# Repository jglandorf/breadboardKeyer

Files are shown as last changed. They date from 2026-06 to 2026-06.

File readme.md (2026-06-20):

## Breadboard Keyer Demo for [ARROW](https://w8rp.org/) Field Day
### A Morse Code Practice Keyer Kit

### See the assembly documentation [here](doc/breadboardKeyer.odt).

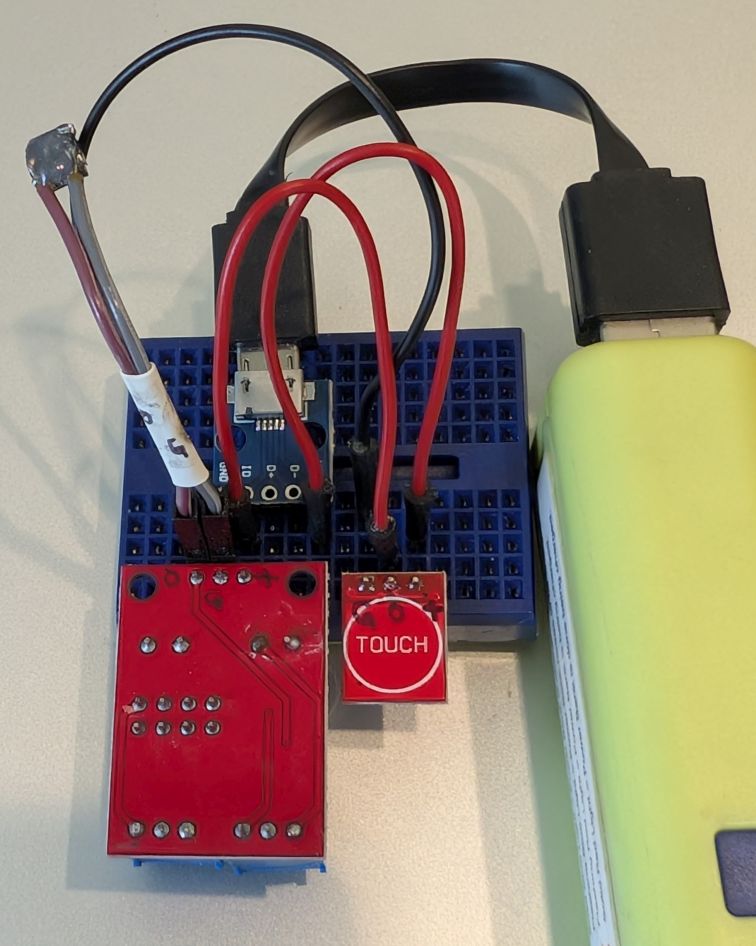
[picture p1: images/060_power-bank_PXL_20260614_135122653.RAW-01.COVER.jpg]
photo, keyer
  

#### Block diagram:
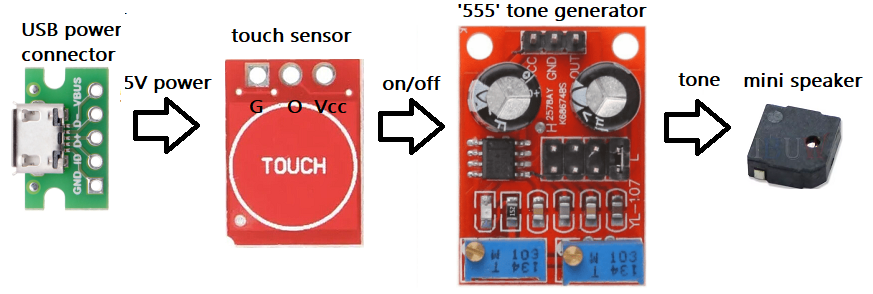
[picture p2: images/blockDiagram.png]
breadboard keyer block diagram
  

a) Power comes from an external USB power bank.  
b) This 5 volts powers the touch sensor-- it doesn’t directly power anything else!  
c) When the sensor is touched, its output turns on the tone generator.  
d) The tone generator output drives the mini speaker.  
Note:  a simplified variant may be built with an [active buzzer](https://www.aliexpress.us/item/3256809353431502.html) instead of the speaker; the '555' tone generator is then not used.

#### [Schematic](./breadboardKeyer.kicad_pro):  
There are four variations:
- micro USB breakout connector with passive speaker  
- USB C breakout connector with passive speaker  
- micro USB breakout connector with active buzzer
- USB C breakout connector with active buzzer

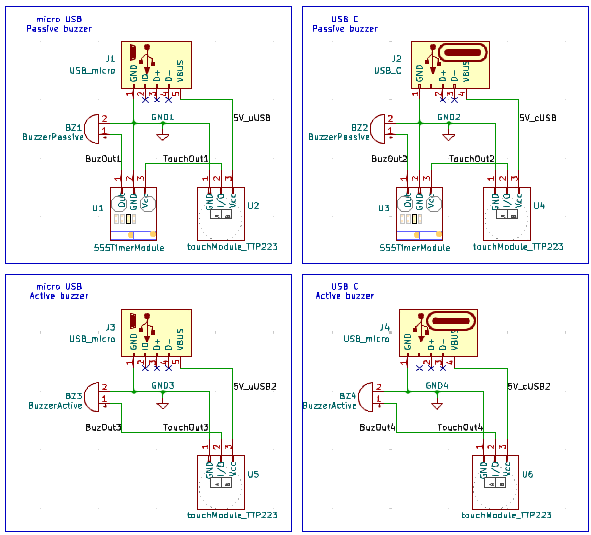
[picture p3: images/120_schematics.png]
breadboard keyer schematic


#### [Breadboard Layouts](./breadboardKeyer.kicad_pro):  
Passive buzzer/speaker with micro USB connector  
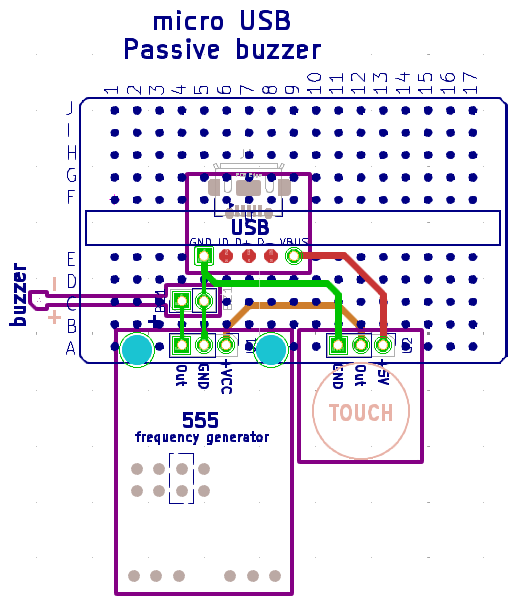
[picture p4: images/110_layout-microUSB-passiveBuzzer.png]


#### Passive buzzer/speaker with USB C connector  
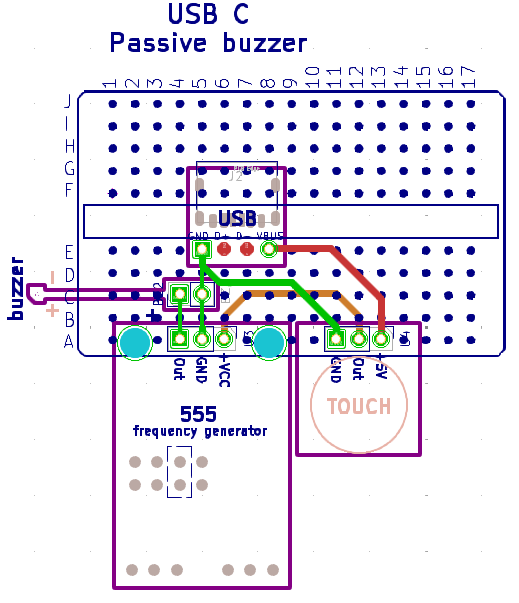
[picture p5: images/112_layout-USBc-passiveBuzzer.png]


#### Active buzzer with micro USB and USB C connectors  
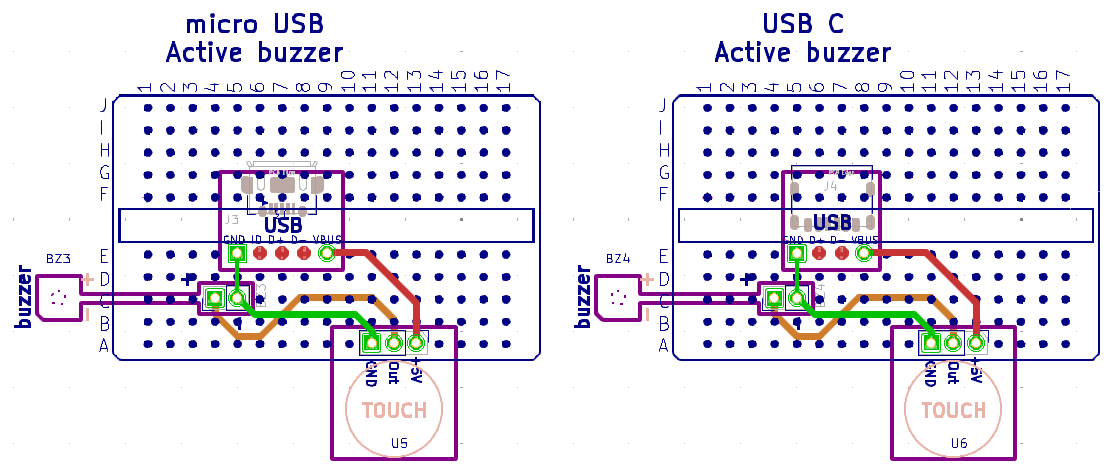
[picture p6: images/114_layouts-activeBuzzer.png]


### Bill-of-materials  
#### Summary for All Variants:  

| Reference | P/N |  Description | Link |  
| --- | --- | --- | ---- |
| †qty ~3-5 | ??? | M-to-M breadboard jumper wires, 5-10cm | [AliExpress](https://www.aliexpress.us/item/3256809296261235.html) |  
| ‡qty 2 | ??? | M-to-M breadboard jumper ribbon, 5-10cm | [Amazon](https://www.amazon.com/dp/B01BV3Z342) |  
| qty 1 | ??? | 170-point mini breadboard | [Amazon](https://www.amazon.com/dp/B0DBDTBDS5?th=1) |  
| qty 1 | ??? | 3x3x3 inch craft paper box | [Amazon](https://www.amazon.com/dp/B0FXFWWB6K?th=1) |  
| qty 1 | 8376 |  ⃰ ⃰ Avery 2x3.5 card stock | e.g., [Amazon](https://www.amazon.com/Avery-Ink-Jet-Printer-Business-28371/dp/B00004Z5DG) |  
| qty ?? | ??? | ⃰heatshrink tubing as needed | [Amazon](https://www.amazon.com/dp/B0GGGY2HFJ) |  
| qty ?? | ??? | ⃰low-temp hot-glue sticks as needed | [Amazon](https://www.amazon.com/Surebonder-Low-Temp-Delicate-Materials-Balloons/dp/B003SBUAAI) |  
| J1, J3 | ??? | micro USB receptacle breakout | [Amazon](https://www.amazon.com/dp/B09XMQRNDL) |  
| J2, J4 | ??? | USB C receptacle breakout | [AliExpress](https://www.aliexpress.us/item/3256804610646385.html) |  
| BZ1, BZ2 | 5020 | 5x5x2mm speaker | [AliExpress](https://www.aliexpress.us/item/3256804070323228.html) |  
| BZ1, BZ2 | ??? | (alternate) PC speaker | [AliExpress](https://www.aliexpress.us/item/3256809886938359.html) |  
| BZ3, BZ4 | 9650 | 9.6x9.6x5mm 3V active buzzer | [AliExpress](https://www.aliexpress.us/item/3256809353431502.html) |  
| U2, U4, U5, U6 | TTP223 | TTP223 touch module | [AliExpress](https://www.aliexpress.us/item/2255800354323887.html) |  
| U1, U3 | NE555 | NE555 module | [AliExpress](https://www.aliexpress.us/item/3256806859546992.html) |  

† Jumper wires used for on-breadboard connections.
  Cut in half, these are soldered to the 5020 or 9650 speakers/buzzers  
‡ Ribbon jumper wires are plugged into the PC speakers/buzzers  
⃰ Use heatshrink to prevent separation of ribbon jumper wires, if needed.  Use hot glue to fill on top of speaker solder joints to prevent wire breakage.  
 ⃰ ⃰ Place card with github link to this page inside the kit's paper box.  Template is [here](doc/businessCards_bbkeyerKit_Avery8376.odt)

You will also need a USB power bank and appropriate USB cable-- not included in the kit.

#### Common to All Variants:  

| Quantity | P/N |  Description | Link |  
| --- | --- | --- | ---- |
| †qty ~3-5 | ??? | M-to-M breadboard jumper wires, 5-10cm | [AliExpress](https://www.aliexpress.us/item/3256809296261235.html) |  
| ‡qty 2 | ??? | M-to-M breadboard jumper ribbon, 5-10cm | [Amazon](https://www.amazon.com/dp/B01BV3Z342) |  
| qty 1 | ??? | 170-point mini breadboard | [Amazon](https://www.amazon.com/dp/B0DBDTBDS5?th=1) |  
| qty 1 | ??? | 3x3x3 inch craft paper box | [Amazon](https://www.amazon.com/dp/B0FXFWWB6K?th=1) |  
| qty 1 of U2, U4, U5, or U6 | TTP223 | TTP223 touch module | [AliExpress](https://www.aliexpress.us/item/2255800354323887.html) |  

† Jumper wires used for on-breadboard connections.
  Cut in half, these are soldered to the 5020 or 9650 speakers/buzzers  
‡ Ribbon jumper wires are plugged into the PC speakers/buzzers  

#### Additional for Each Variant:
#### Micro USB breakout connector with passive speaker  

| Reference | P/N |  Description | Link |  
| --- | --- | --- | ---- |
| J1 | ??? | micro USB receptacle breakout | [Amazon](https://www.amazon.com/dp/B09XMQRNDL) |  
| BZ1 | 5020 | 5x5x2mm speaker | [AliExpress](https://www.aliexpress.us/item/3256804070323228.html) |  
| BZ1 | ??? | (alternate) PC speaker | [AliExpress](https://www.aliexpress.us/item/3256809886938359.html) |  
| U1 | NE555 | NE555 module | [AliExpress](https://www.aliexpress.us/item/3256806859546992.html) |  

#### USB C breakout connector with passive speaker  

| Reference | P/N |  Description | Link |  
| --- | --- | --- | ---- |
| J4 | ??? | USB C receptacle breakout | [AliExpress](https://www.aliexpress.us/item/3256804610646385.html) |  
| BZ2 | 5020 | 5x5x2mm speaker | [AliExpress](https://www.aliexpress.us/item/3256804070323228.html) |  
| BZ2 | ??? | (alternate) PC speaker | [AliExpress](https://www.aliexpress.us/item/3256809886938359.html) |  
| U3 | NE555 | NE555 module | [AliExpress](https://www.aliexpress.us/item/3256806859546992.html) |  

#### Micro USB breakout connector with active buzzer  

| Reference | P/N |  Description | Link |  
| --- | --- | --- | ---- |
| J3 | ??? | micro USB receptacle breakout | [Amazon](https://www.amazon.com/dp/B09XMQRNDL) |  
| BZ3 | 9650 | 9.6x9.6x5mm 3V active buzzer | [AliExpress](https://www.aliexpress.us/item/3256809353431502.html) |  

#### USB C breakout connector with active buzzer  

| Reference | P/N |  Description | Link |  
| --- | --- | --- | ---- |
| J4 | ??? | USB C receptacle breakout | [AliExpress](https://www.aliexpress.us/item/3256804610646385.html) |  
| BZ4 | 9650 | 9.6x9.6x5mm 3V active buzzer | [AliExpress](https://www.aliexpress.us/item/3256809353431502.html) |

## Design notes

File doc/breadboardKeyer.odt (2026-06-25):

Breadboard Keyer Demo for ARROW Field Day

A Morse Code Practice Keyer Kit


© 2026 AC8ES

1. Parts
  a. 3x jumper wires (colors may vary)
  b. 1x solderless breadboard
  c. 1x mini speaker
  d. 1x USB power connector module
  e. 1x touch sensor
  f. 1x tone generator ☞ Parts’ appearances and colors may vary.
  g. not included: USB power bank
  h. not included: USB power cable
2. What is a solderless breadboard?
  a. It let’s you easily mount components and connect them together. Each vertical section of five holes are electrically connected via a metal strip inside. There is no connection between adjacent metal strips. In the “old days”

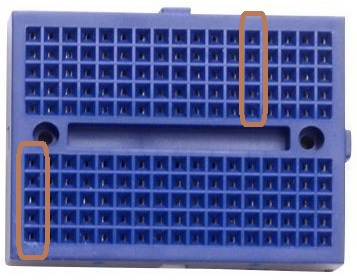
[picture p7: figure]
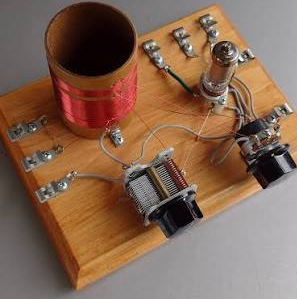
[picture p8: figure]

    Why the term “breadboard”? - From the 1920’s, people screwed wire clips and vacuum tubes (sockets) and other components to actual wooden breadboards to build circuits. (images from https://www.facebook.com/groups/ARNewsline/posts/10158915416309210, https://www.ebay.com/itm/253106065602)
  b. Each component or jumper wire has a pin that can plug into a hole into the breadboard.

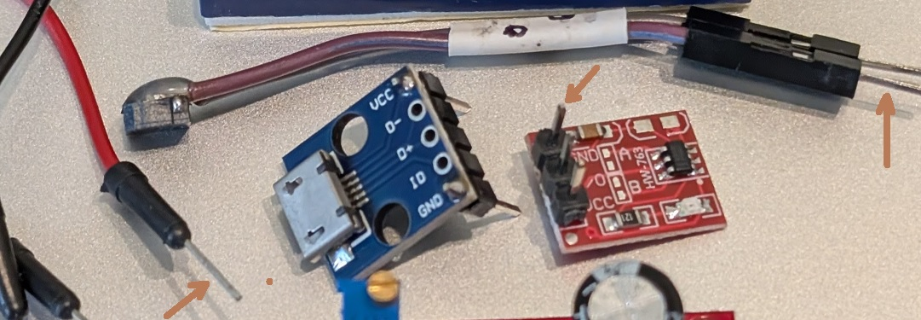
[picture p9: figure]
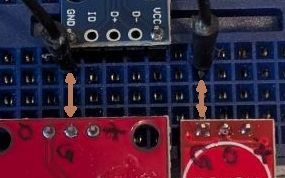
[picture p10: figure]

  a. Here, the pins labeled “GND”, “G”, and “G” are all connected. - The black jumper wire connects the pins labeled “G”. - The breadboard itself connects “GND” to “G”.
3. Keyer Block Diagram
  a. Power comes from an external USB power bank.


  b. This 5 volts powers the touch sensor-- it doesn’t directly power anything else!
  c. When the sensor is touched, its output supplies power to the tone generator, which turns it on.
  d. The tone generator output drives the mini speaker.  (images from: USB: https://www.pololu.com/product/2586, touch: https://wled.discourse.group/t/sp511e-ttp223-touchpad-tutorial/8725, 555: https://rhoelect.gr/product/ne555-timer-module-yl-107/, speaker: https://www.aliexpress.us/item/3256809353431502.html)
4. Start assembly by mounting the modules onto the breadboard. ☞ Refer to Appendix: Pictorial Layout for a pictographic layout. ☞ These directions build the “Passive buzzer” variant in Appendix: Schematic Variations; a slightly simpler version can be built if an “active buzzer” is available.

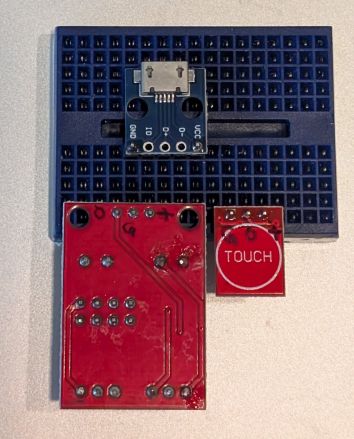
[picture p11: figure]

  a. Mount the tone generator-- “parts upside down”-- with the pins in the bottom row. The pin on the left, “O”, should be in the fourth column. ☞ It will be helpful to mark the pins as shown:

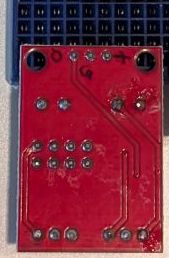
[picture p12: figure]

  b. Mount the USB connector module, “parts on top”, in the top row of the bottom half of the breadboard. Its left-most pin, “GND”, should also be in the fourth row. This way, “GND” and “G” are connected via the metal strip inside the breadboard.

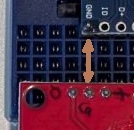
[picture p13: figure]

  c. Mount the touch module, “parts upside down”, on the bottom row, next to the tone generator. ☞ Again, it will be helpful to mark the pins as shown:

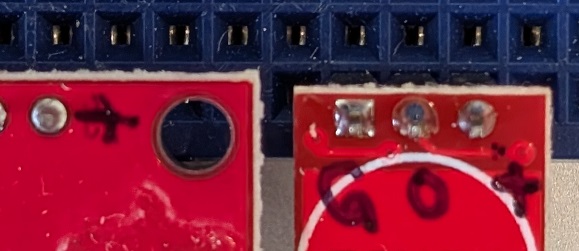
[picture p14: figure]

5. Add jumper wires.
  a. Using the 2nd row of the breadboard’s bottom half, connect a jumper wire from “GND” (USB module) to “G” of the touch module.

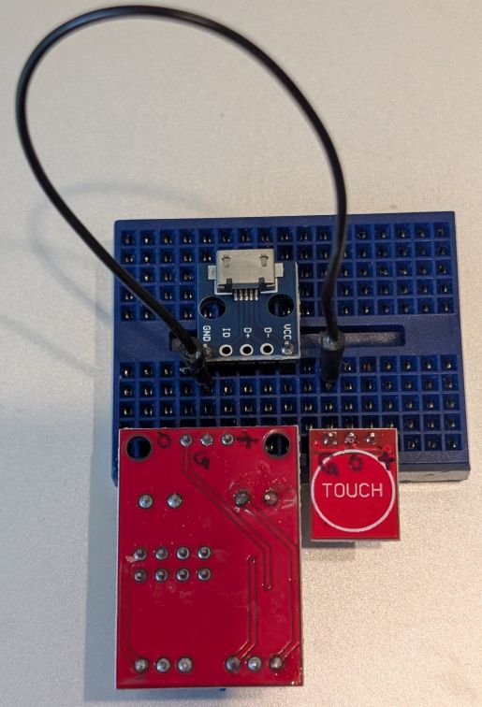
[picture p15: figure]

  b. Using the 3rd row of the breadboard’s bottom half, connect a jumper wire from “VBUS” (USB module) to “+” of the touch module. ☞ The USB module you have may differ from what’s shown. Just connect “VBUS” or “V” or the equivalent pin.

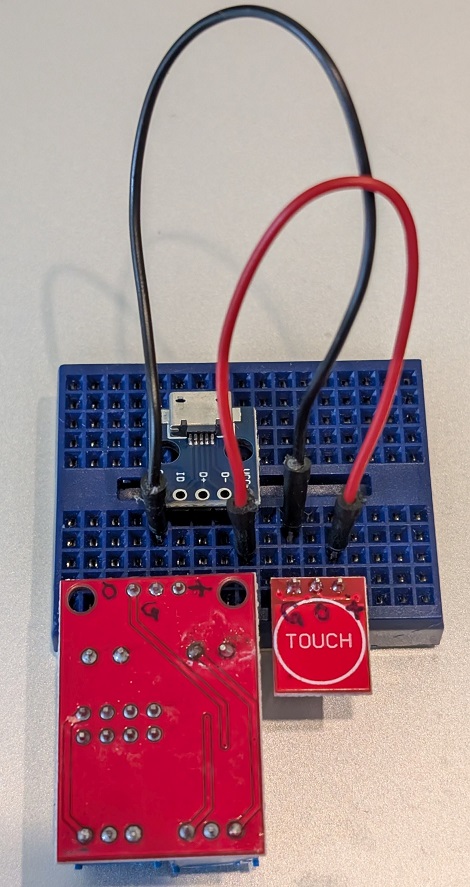
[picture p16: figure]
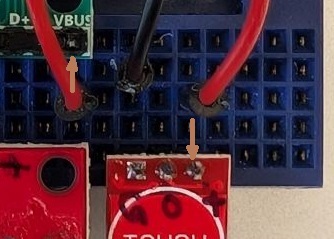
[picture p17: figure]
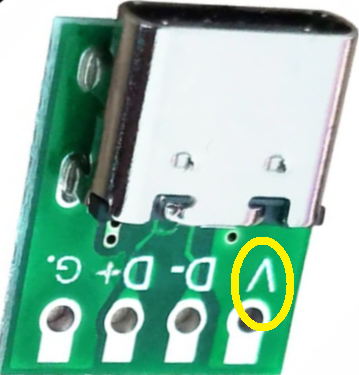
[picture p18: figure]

  c. Using the 4th row of the breadboard’s bottom half, connect a jumper wire from “+” (tone generator module) to “O” of the touch module. ☞ Remember, the output of the touch module actually powers the tone generator.

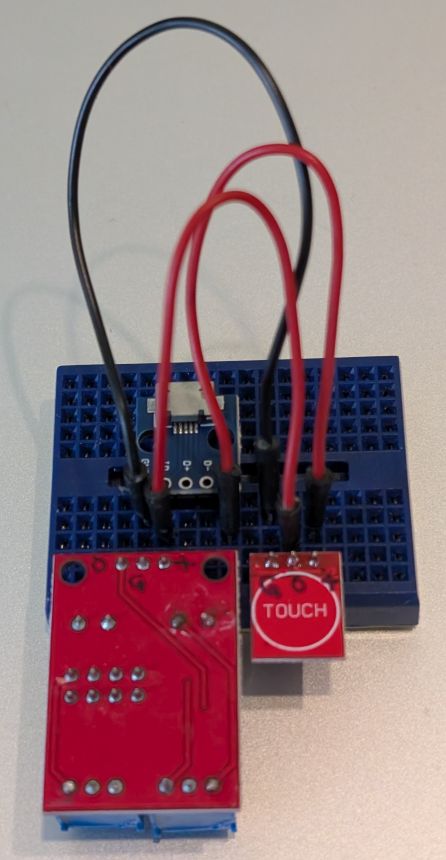
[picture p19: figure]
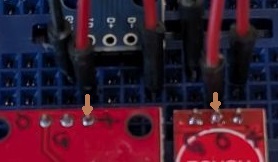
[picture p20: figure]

6. Add speaker.
  a. Again using the 4th row of the breadboard’s bottom half, connect the speaker’s “G” pin to the “G” breadboard column. Connect the speaker’s “O” lead to the “O” pin of the tone generator module. ☞ If the speaker leads are not marked, then they are interchangeable.

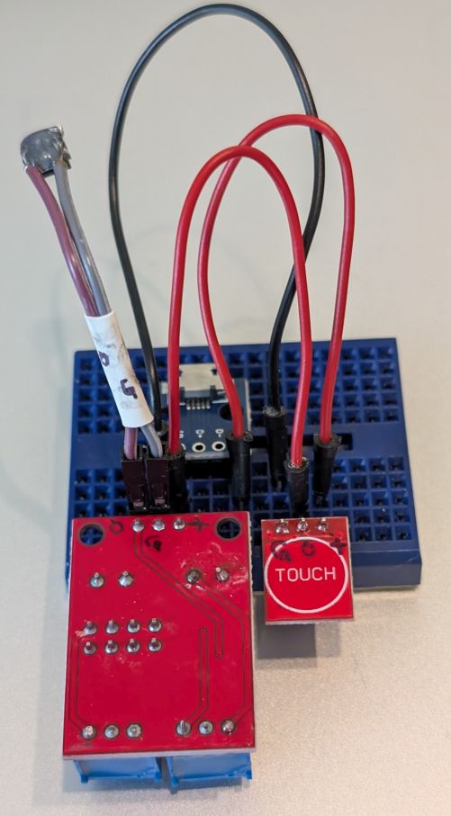
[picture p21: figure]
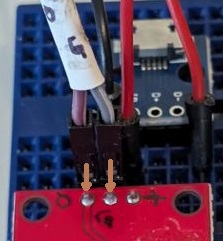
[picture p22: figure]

7. Connect USB power bank.
  a. Make sure the power bank is off.
  b. Plug a USB power cable between a power bank and the USB module.

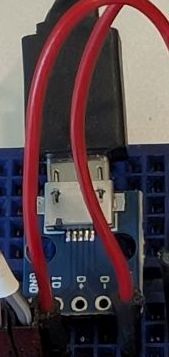
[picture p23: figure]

8. Test!
  a. Turn on the power bank.
  b. Tap the touch module.
    1. The red LED on the touch module’s “part’s side” will light.
    2. The speaker will beep-- listen carefully; it’s a bit quiet.
  c. ☞If the sensor turns on when your finger is hovering just above it, you can affix a small square of cardboard on top of the sensor.
9. International Morse Code
    1. The length of a dot is one unit.
    2. A dash is three units.
    3. The space between parts of the same letter is one unit.
    4. The space between letters is three units.

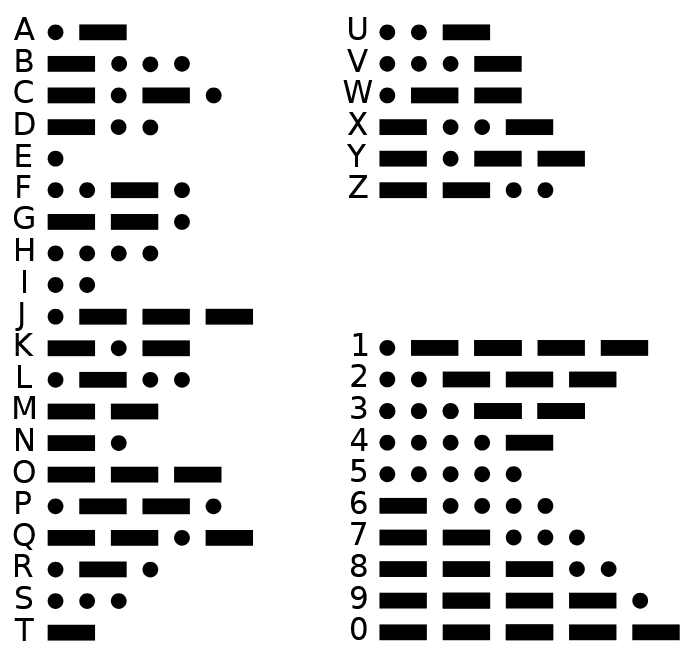
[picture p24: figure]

    5. The space between words is seven units.

### Appendix: Pictorial Layout


### Appendix: Schematic Variations


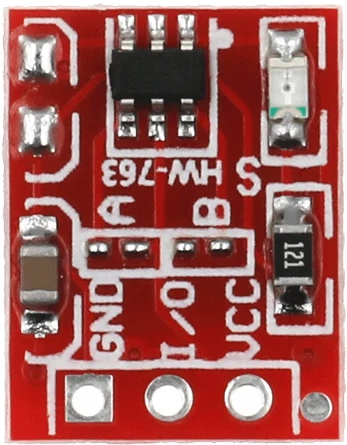
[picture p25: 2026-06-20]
images/touchModule_TTP223-front.png

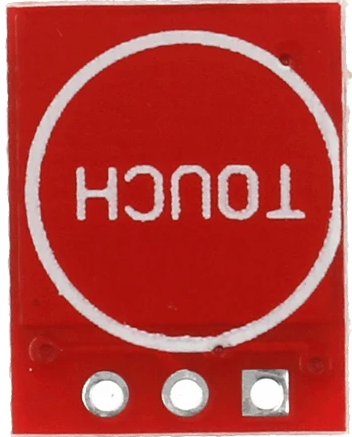
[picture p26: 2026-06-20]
images/touchModule_TTP223-back.png

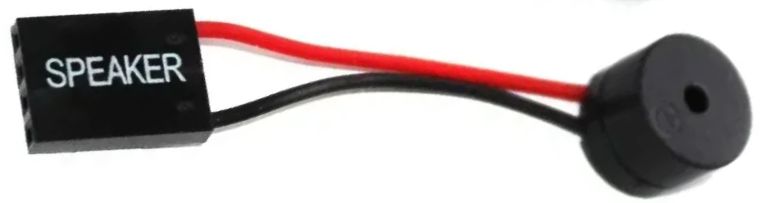
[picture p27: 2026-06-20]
images/speaker_PC_dia12mm.jpg

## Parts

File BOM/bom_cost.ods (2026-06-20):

Breadboard keyer kit BOM costs
description | link | qty | order cost | order qty | cost each | ext’d cost
Variant 1: micro USB with passive PC speaker
breadboard | Amazon (https://www.amazon.com/dp/B0DBDTBDS5) | 1 | $8.00 | 12 | 0.670 | $0.67
jumper wires | AliExpress (https://www.aliexpress.us/item/3256809296261235.html) | 5 | $2.50 | 65 | 0.040 | $0.20
jumper wires | Amazon (https://www.amazon.com/dp/B01BV3Z342) | 2 | $7.00 | 120 | 0.060 | $0.12
paper box | Amazon (https://www.amazon.com/dp/B0FXFWWB6K) | 1 | $9.00 | 25 | 0.360 | $0.36
touch module | AliExpress (https://www.aliexpress.us/item/2255800354323887.html) | 1 | $1.00 | 10 | 0.100 | $0.10
micro USB | AliExpress (https://www.amazon.com/dp/B09XMQRNDL) | 1 | $4.55 | 10 | 0.460 | $0.46
PC speaker | AliExpress (https://www.aliexpress.us/item/3256809886938359.html) | 1 | $1.95 | 10 | 0.200 | $0.20
NE555 module | AliExpress (https://www.aliexpress.us/item/3256806859546992.html) | 1 | $3.60 | 5 | 0.720 | $0.72
0.1” header pins | AliExpress (https://www.aliexpress.us/item/3256807383526945.html) | 5 | $1.52 | 400 | 0.0038 | $0.02
heatshrink tubing | Amazon (https://www.amazon.com/dp/B0GGGY2HFJ) | 1 | $6.19 | 210 | 0.0295 | $0.03
low-temp hot glue | Amazon (https://www.amazon.com/Surebonder-Low-Temp-Delicate-Materials-Balloons/dp/B003SBUAAI) | 0.25 | $2.60 | 15 | 0.1733 | $0.04
Avery 2x3.5 card stock | Amazon (https://www.amazon.com/Avery-Ink-Jet-Printer-Business-28371/dp/B00004Z5DG) | 1 | $6.00 | 100 | 0.0600 | $0.06
total |  |  | $37.60 |  |  | $2.83
total w/ 6% MI sales tax |  |  | $39.86 |  |  | $3.00
Alternate parts |  |  |  |  |  |  | Δcost
NE555 module | AliExpress (https://www.aliexpress.us/item/2251801856883982.html) | 1 | $3.31 | 10 | $0.33 | $0.33 | -$0.39
NE555 module | AliExpress (https://www.aliexpress.us/item/3256805926048938.html) | 1 | $3.43 | 10 | $0.34 | $0.34 | -$0.38
9650 active buzzer | AliExpress (https://www.aliexpress.us/item/3256809353431502.html) | 1 | $2.48 | 5 | $0.50 | $0.50 | $0.30
5020 passive speaker | AliExpress (https://www.aliexpress.us/item/3256804070323228.html) | 1 | $1.67 | 5 | $0.33 | $0.33 | $0.13
passive speaker w header | AliExpress (https://www.aliexpress.us/item/3256806596283860.html) | 1 | $2.75 | 10 | $0.28 | $0.28 | $0.08
USB C breakout ( no pins!) | AliExpress (https://www.aliexpress.us/item/3256804610646385.html) | 1 | $4.63 | 10 | $0.46 | $0.46 | $0.00

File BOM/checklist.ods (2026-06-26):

 | Breadboard Keyer Kit Checklist
 | Variants 1, 2: 555 tone generator with passive PC speaker
item |  | qty | goes where | prep | prep
1 | paperboard box | 1 |  | unfold
2 | box write-on sticker | 1 | on box lid | peel, stick
3 | 2x3.5” info card | 1 | in box
4 | breadboard | 1 | in box
5 | jumper wires | 3 | in box
6 | touch module | 1 | in box | mark pins
7 | USB breakout | 1 | in box | mark pins | remove middle pins
8 | 555 module | 1 | in box | mark pins | move header
9 | PC speaker | 1 | in box

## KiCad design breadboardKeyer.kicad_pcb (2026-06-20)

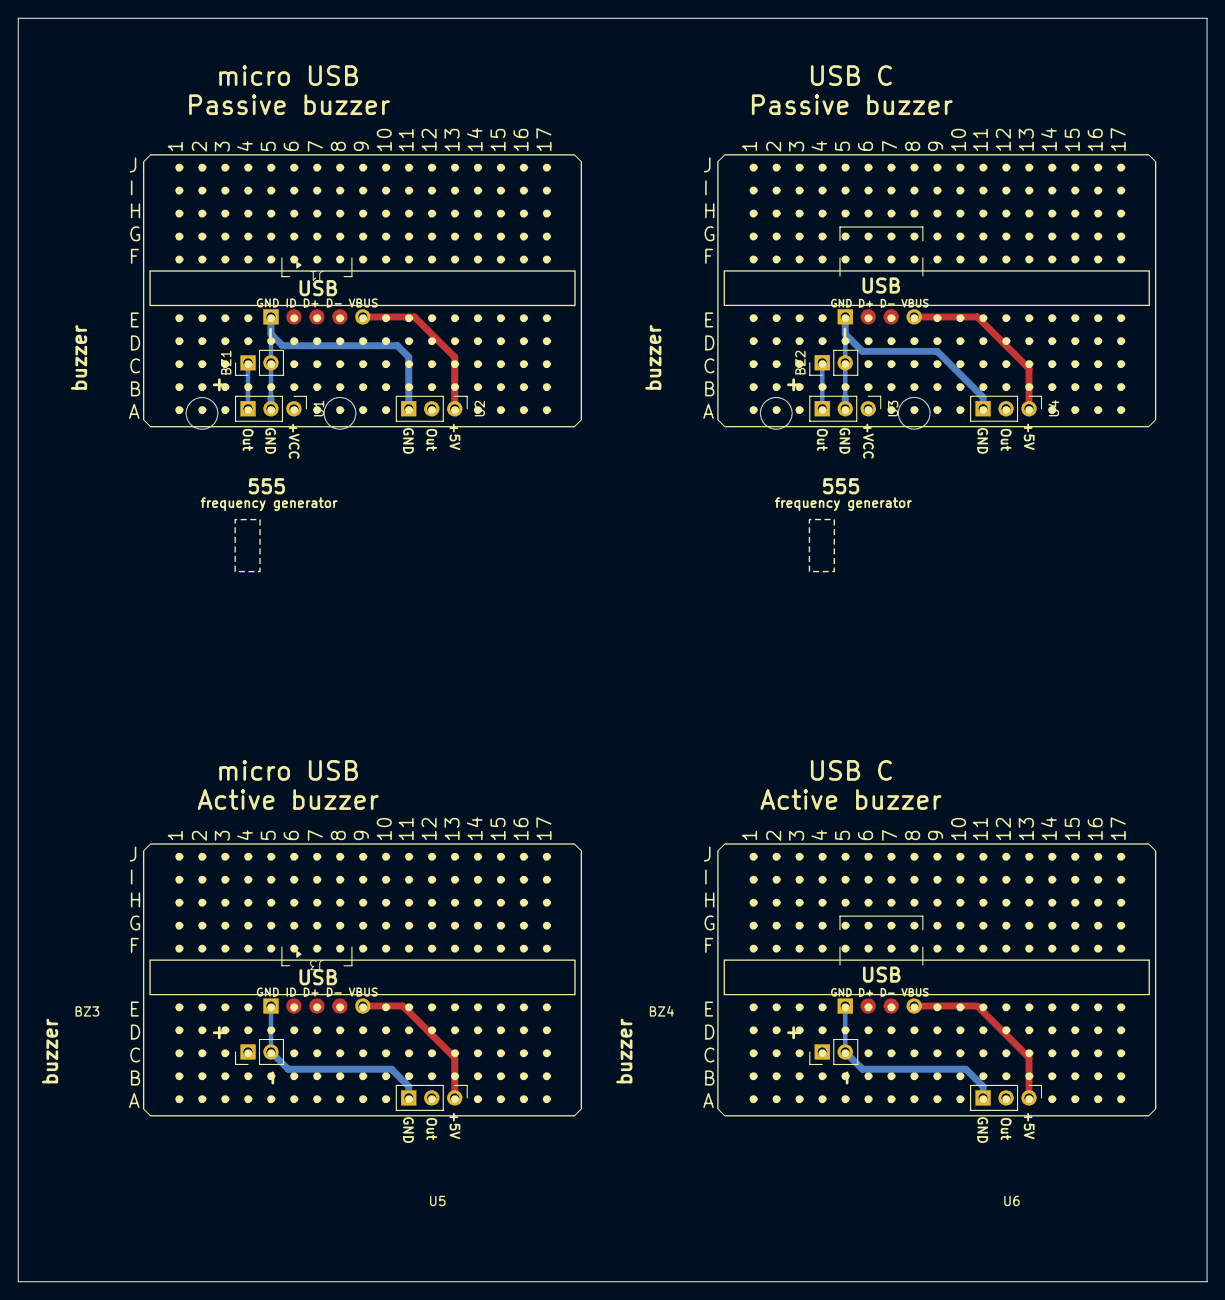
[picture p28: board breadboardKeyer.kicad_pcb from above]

Board: 4 copper layers, 131.4 x 139.7 mm, 18 parts (0 on the bottom side), 14 nets.

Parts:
BZ1, BZ2: BuzzerPassive; Buzzer2020_Passive_1x02_P2.54mm_Horizontal
BZ3, BZ4: BuzzerActive; Buzzer5050_Active_1x02_P2.54mm_Horizontal
J1, J3: USB_micro; microUSBBreakout
J2: USB_C; cUSBBreakout
J4: USB_micro; cUSBBreakout
U1, U3: 555TimerModule; 555timerModule_1x03_P2.54mm_20z30mm
U2, U4, U5, U6: touchModule_TTP223; TTP223TouchModule_1x03_P2.54mm_10z14mm
Z1, Z2, Z3, Z4: LOGO; breadboard170_FSilkscreen

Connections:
/5V_cUSB: J2.4 (VBUS), U4.3 (Vcc)
/5V_cUSB2: J4.4 (VBUS), U6.3 (Vcc)
/5V_uUSB: J1.5 (VBUS), U2.3 (Vcc)
/5V_uUSB2: J3.5 (VBUS), U5.3 (Vcc)
/BuzOut1: BZ1.1 (+), U1.1 (Out)
/BuzOut2: BZ2.1 (+), U3.1 (Out)
/BuzOut3: BZ3.1 (+), U5.2 (I/O)
/BuzOut4: BZ4.1 (+), U6.2 (I/O)
/TouchOut1: U1.3 (Vcc), U2.2 (I/O)
/TouchOut2: U3.3 (Vcc), U4.2 (I/O)
GND1: BZ1.2 (-), J1.1 (GND), U1.2 (GND), U2.1 (GND)
GND2: BZ2.2 (-), J2.1 (GND), U3.2 (GND), U4.1 (GND)
GND3: BZ3.2 (-), J3.1 (GND), U5.1 (GND)
GND4: BZ4.2 (-), J4.1 (GND), U6.1 (GND)

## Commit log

2026-06-20 Initial commit. "Breadboard Keyer Demo for ARROW Field Day"
    [breadboardKeyer.kicad_pcb, breadboardKeyer.kicad_sch]
2026-06-20 Added BOM+costs in BOM/bom_cost.ods.
    [bom_cost.ods]
2026-06-25 Add assembly doc page numbers.
2026-06-26 Add quick checklist
    [checklist.ods]

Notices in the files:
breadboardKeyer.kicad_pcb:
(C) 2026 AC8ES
